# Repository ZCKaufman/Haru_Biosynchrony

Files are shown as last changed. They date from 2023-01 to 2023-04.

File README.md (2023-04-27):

# Haru_Biosynchrony
The Haru Biosynchrony detection device is a pair of devices created by Cameron Middleton, Carmen Hernandez, Dawson Thompson, Jonathan Ott, and Zachary Kaufman at Indiana University for the Intelligent Systems Engineering Senior Capstone (ENGR-E490/E491) course. The device is designed to be used with the Haru social desktop robot prototype by Honda Research Institute, and was created as a tool for the R-House Human-Robot Interaction lab to use for their studies involving intergenerational synchrony during interactions with Haru. 

Contents:
- Hardware Specifications
- Assembly Instructions
- Demo Instructions
- Using the Device
- Running the Code
- Understanding the Output

## Hardware Specifications

## Assembly Instructions

## Demo Instructions

## Using the Device
- This system uses two devices and finds relative bio-synchrony between them. Ensuring that both devices are currently placed on the participants is important for quality metrics of synchrony. 
1. Place the compute module on the top of your non-dominant wrist and secure with velcro strap firmly but not uncomfortably
2. Place the PPG sensor (the one with purple and red wires) on your index finger by slipping your index finger inside the black sleeve so that the red sensor is on the padding at the bottom of your finger
3. Place the PPG sensor (the one with the two thin wires) on your middle and forefinger by slipping those fingers into the black sleeves so that the metal sensors are on the bottom of the center of your finger
4. Place your non-dominant hand (the one with the sensors on it) at your waist if standing, or on your lap if sitting
    - Note: It is best for sensor resolution if the sensors are not moved a lot during the activity, try encouraging participants to keep their non-dominant hand at this position and to use their dominant hand for the activity
5. Now plug in the compute module to the Haru Zotac computer through a USB port and follow the `Running the Code` instructions

## Running the Code
- System Requirements
    - Python 3.10+
    - Ubuntu 20.04
    - ROS Noetic
- Instructions
    1. Open the Arduino IDE in two separate windows
    2. Open a terminal window and run the command `roscore`
    3. In the first window open the file `A_ROS_Arduino.ino` and in the second window open the file `B_ROS_Arduino.ino`
    4. In both windows make sure that the selected board (under Tools) is "Arduino Micro" and the selected port is the port that the Arduino is plugged into
    5. Click the blue/green "Upload" button in the upper left corner of the screen in both windows
    6. Now open two new tabs/windows in terminal and type in the following command for both devices: 'rosrun rosserial_arduino serial_node.py __name:="DevA" _port:=/dev/ttyACM0`
        NOTE: There are two underscores before `name` and one before `port`
        NOTE: Your port may be different, use the one found in the Arduino window for the device you are using under "Tools"
        - Run the same command again but rename the second device to `DevB` and change the port to whatever port the second device is plugged into
    7. Open the Haru_Biosynchrony repository in VSCode 
    8. Open a terminal within VSCode and run the following command `pyenv activate haru_sync`, this will activate the Haru Synchrony Python environment. This environment is installed on the Zotac machines from Honda
    9. Now run the code by entering the following command `python Robot_Code/synchrony.py`
    10. The code should now be running. Every 5 seconds a synchrony metric will be published to ROS and printed into the VS Code terminal
    11. To stop and start over, just click ctrl+c and rerun the command from step 9 (ix)

## Understanding the output
The output from this program will be a metric of synchrony called a Pearson Correlation and it will update the metric every 5 seconds. There will be a score published for heart rate and GSR separately. The metric will be published on ROS as well as printed to the terminal running the program. 
- Negative Score (-1 to 0)
    - A negative score means that the subjects are experiencing negative synchrony, meaning that their heart rate or GSR has an inverse correlation. An inverse correlation means that the subjects' heart rate or GSR data is trending in opposite values from each other. A score of less than -0.5 represents a strong inverse correlation.
- Zero Score (0)
    - A 0 score means that the two participants are neither in sync nor moving out of sync. Their heart rate and GSR data is not correlated.
- Positive Score (0 to 1)
    - A positive score means that the subjects are experiencing synchrony, meaning that their heart rate or GSR has a direct correlation. A score of greater than 0.5 represents a strong correlation.

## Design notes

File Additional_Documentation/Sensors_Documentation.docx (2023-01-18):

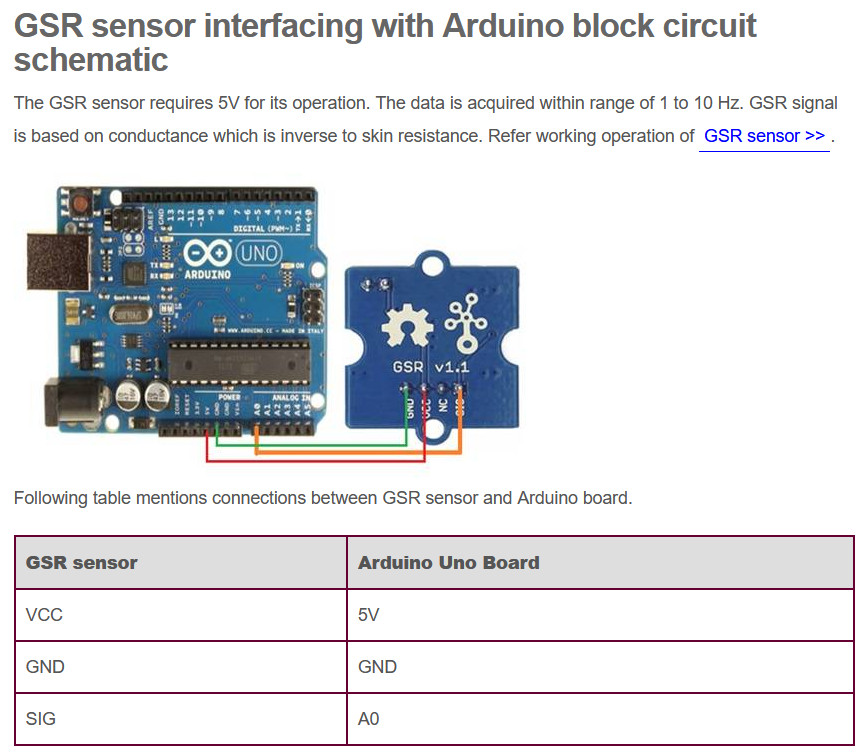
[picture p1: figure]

Source: GSR Interfacing with Arduino Controllers (https://www.rfwireless-world.com/Terminology/GSR-sensor-interfacing-with-Arduino-Code-and-schematic.html)

Sparkfun Pulse Oximeter is more complex than the above GSR board as it interfaces with the Arduino over I2C.

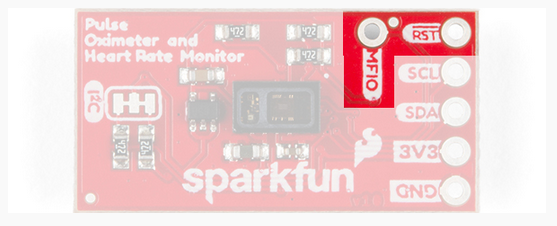
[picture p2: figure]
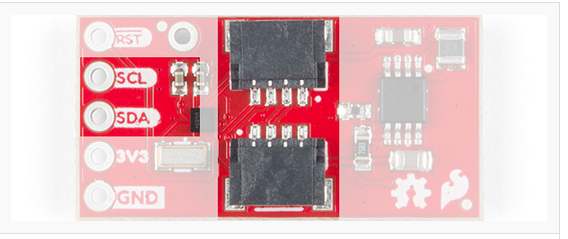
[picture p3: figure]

The board shown is the full Pulse Oximeter. It has a total of 6 pins that need to be connected. 3v3 and Gnd are exactly what they sound like, SCL and SDA form the I2C link to the Arduino (see I2C wiring for Arduino below), and RST and MFIO do not need to be used directly by the end user but must be connected to 2 Digital Arduino pins so the library can control them. The SDA and SCL pins must be connected to the respective SDA and SCL pins on the arduino. I2C works via addressing. This means theoretically, you can have more than one I2C device on a given I2C communication channel. For our project, we will only have the 1 I2C device per arduino, so its unlikely for us to need to deal with this.

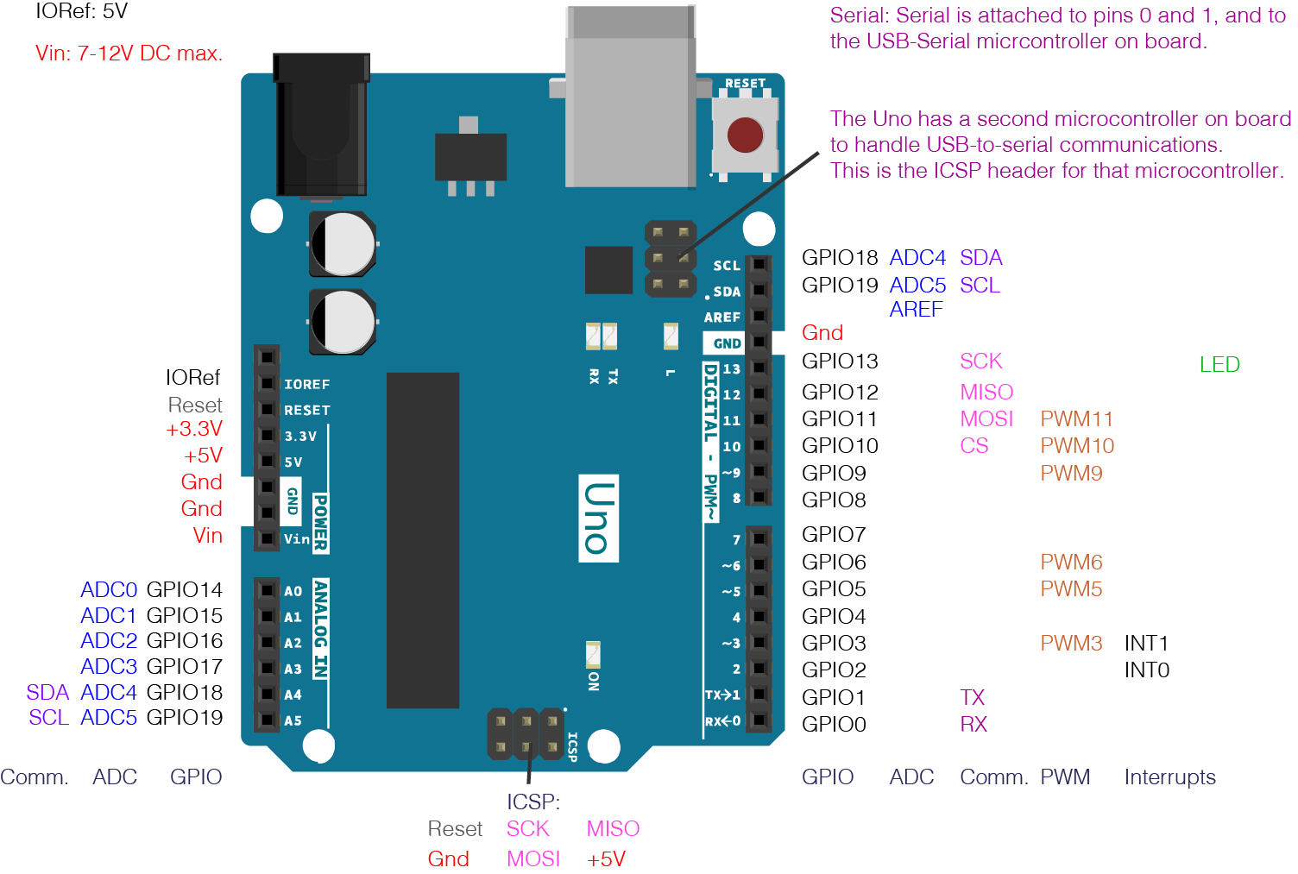
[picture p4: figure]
enter image description here

Once the appropriate connections are made, most of the complexity of the sensor is handled by the provided library. Below is an example of how you would configure the library initially for use. DEF_ADDR is the I2C address used by the sensor. This value should most likely only be what is displayed below, however, another look at the sensor documentation could reveal otherwise. resPin and mfioPin are the digital pins on the Arduino that the respective pins described above are connected to. These values can vary as long as they are updated in the code appropriately. In order to properly pull data from the sensor, you must use <SparkFun_Bio_Sensor_Hub_Library.h>. Examples on how to properly pull data are provided in the source link below.

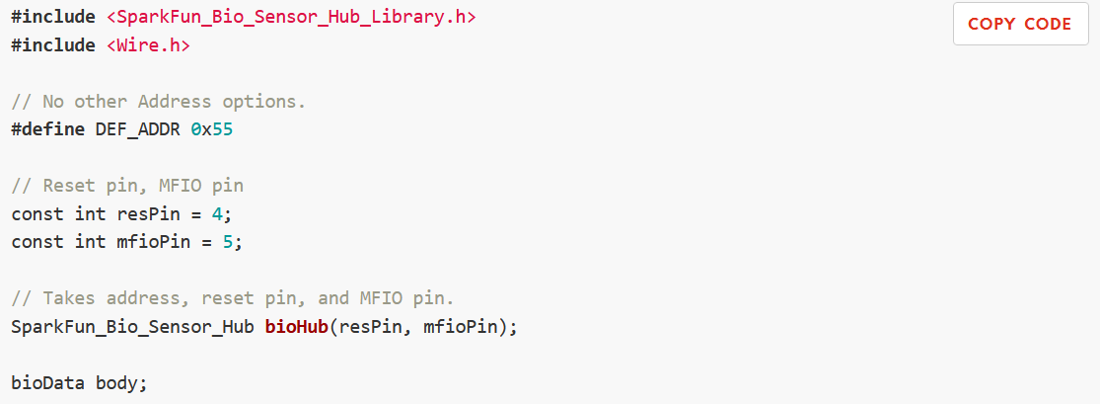
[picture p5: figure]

Source: SparkFun Pulse Oximeter and Heart Rate Monitor Hookup Guide (https://learn.sparkfun.com/tutorials/sparkfun-pulse-oximeter-and-heart-rate-monitor-hookup-guide/all)

Code Examples: SparkFun_Pulse_Oximeter_Heart_Rate_Sensor (https://github.com/sparkfun/SparkFun_Pulse_Oximeter_Heart_Rate_Sensor)

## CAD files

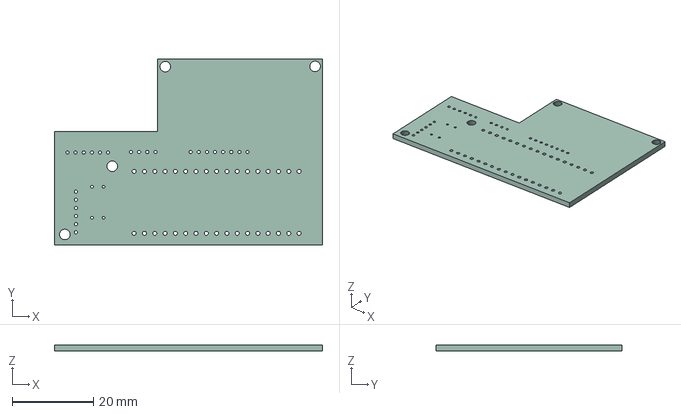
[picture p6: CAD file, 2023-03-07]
Hardware/Prototype_2/PCB/PCB.step
66.0 x 45.7 x 1.60 mm

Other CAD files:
Hardware/Prototype_1/Arduino_Uno v1.f3d
Hardware/Prototype_1/Assembly v19.f3z
Hardware/Prototype_1/Body v21.f3d
Hardware/Prototype_1/Cover v6.f3d
Hardware/Prototype_2/PPG Sleeve v2.f3d
Hardware/Prototype_2/Strain Relief v5.f3d

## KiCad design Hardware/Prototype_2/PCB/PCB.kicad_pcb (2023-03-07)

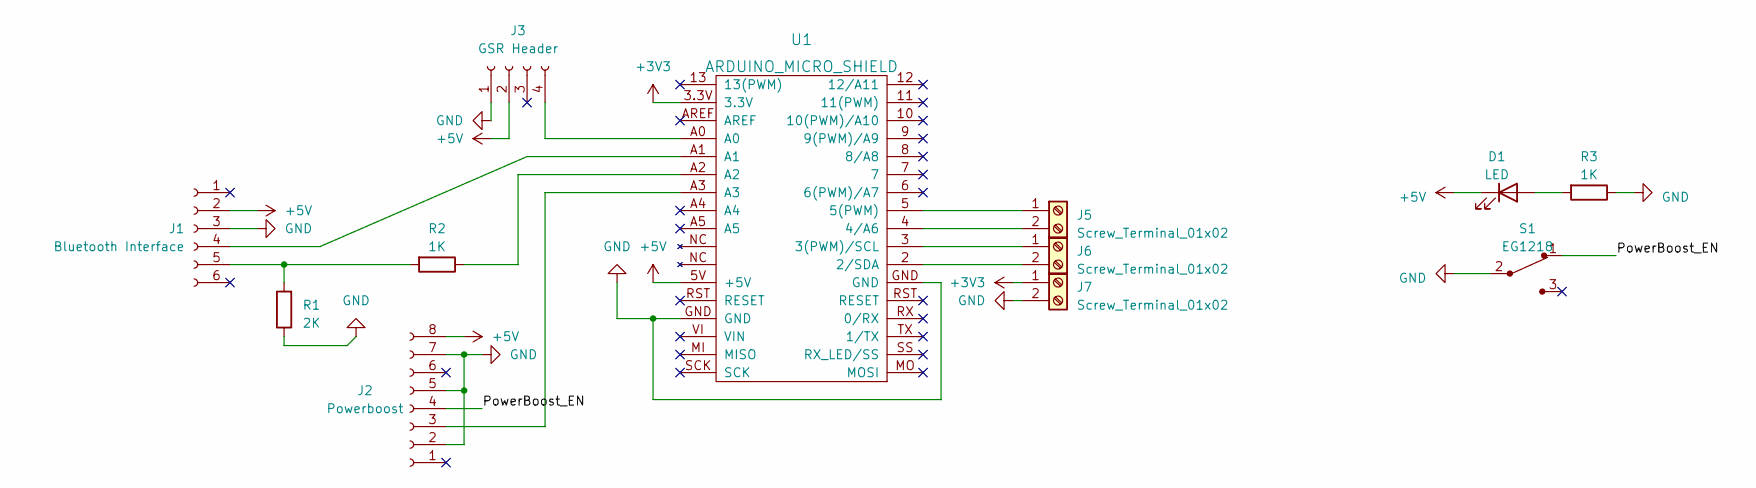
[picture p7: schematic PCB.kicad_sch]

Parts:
D1: LED; LED_D3.0mm_Horizontal_O1.27mm_Z6.0mm
J1: Bluetooth Interface; PinHeader_1x06_P2.00mm_Horizontal
J2: Powerboost; PinSocket_1x08_P2.54mm_Vertical
J3: GSR Header; PinHeader_1x04_P2.00mm_Vertical
J5, J6, J7: Screw_Terminal_01x02; TerminalBlock_Altech_AK300-2_P5.00mm
R1: 2K; R_Axial_DIN0204_L3.6mm_D1.6mm_P7.62mm_Horizontal
R2, R3: 1K; R_Axial_DIN0204_L3.6mm_D1.6mm_P7.62mm_Horizontal
S1: EG1218; Switch_Slide_11.6x4mm_EG1218; MPN EG1218; Digi-Key_PN EG1903-ND
U1: ARDUINO_MICRO_SHIELD

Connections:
+3V3: J7.1, U1.3.3V
+5V: D1.1 (K), J1.2, J2.8, J3.2, U1.5V (+5V)
/PowerBoost_EN: J2.4, S1.1
GND: J1.3, J2.2, J2.5, J2.7, J3.1, J7.2, R1.1, R3.1, S1.2, U1.GND
unnamed: D1.2 (A), R3.2
unnamed: J1.4, U1.A1
unnamed: J1.5, R1.2, R2.2
unnamed: J2.3, U1.A3
unnamed: J3.4, U1.A0
unnamed: J5.1, U1.5 (5(PWM))
unnamed: J5.2, U1.4 (4/A6)
unnamed: J6.1, U1.3 (3(PWM)/SCL)
unnamed: J6.2, U1.2 (2/SDA)
unnamed: R2.1, U1.A2

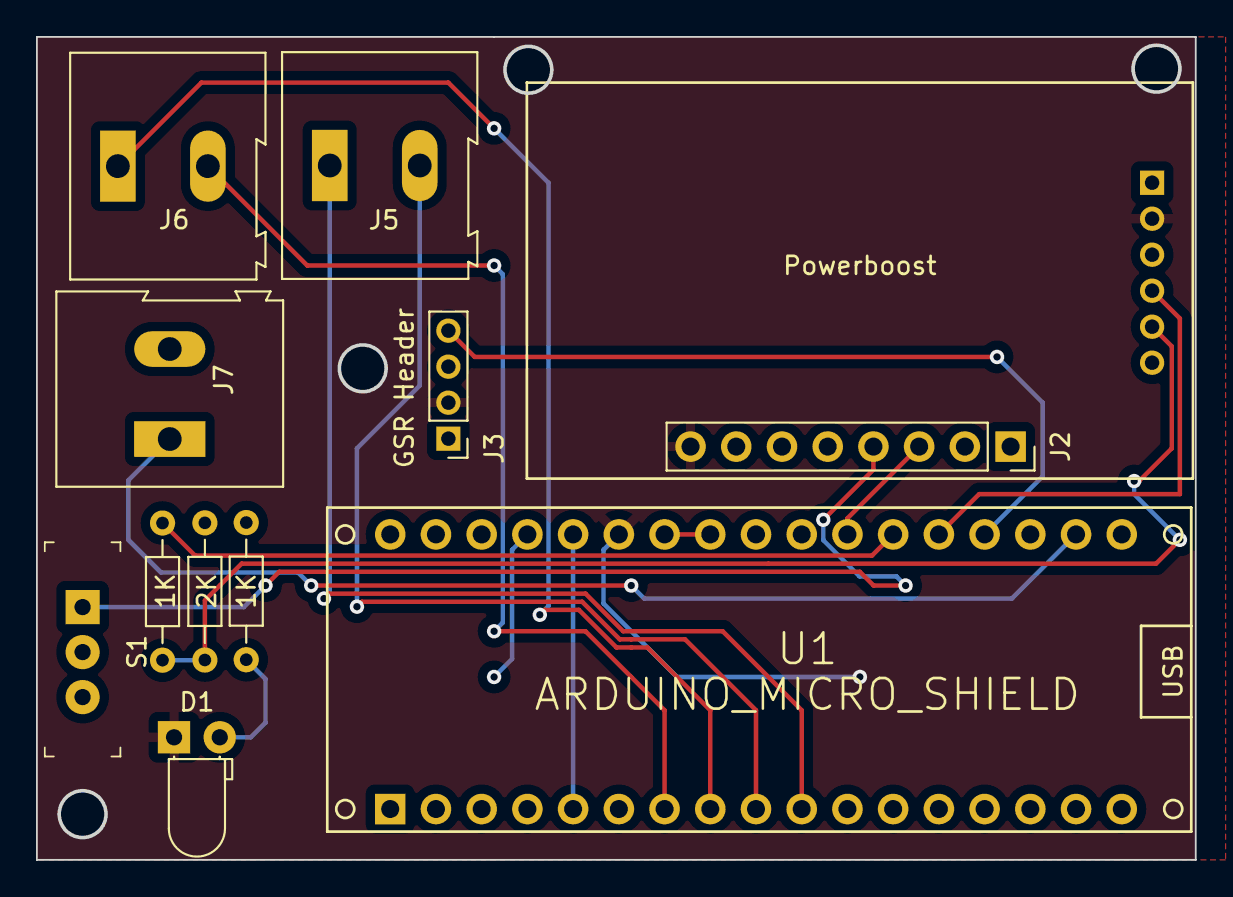
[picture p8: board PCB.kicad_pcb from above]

Board: 2 copper layers, 64.4 x 45.7 mm, 12 parts (1 on the bottom side), 14 nets.

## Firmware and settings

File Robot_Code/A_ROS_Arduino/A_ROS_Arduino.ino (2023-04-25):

#include <SparkFun_Bio_Sensor_Hub_Library.h>
#define USE_USBCON
#include <Wire.h>
#include <ros.h>
#include <std_msgs/Int16.h>

// No other Address options. Does not need to be changed ever.
#define DEF_ADDR 0x55
//encoder_method = "utf-8"

// Creates ROS node handle, which takes care of serial communication and creating publishers and subscribers
ros::NodeHandle nh;
std_msgs::Int16 str_msg;

// Instantiate ROS publishers
ros::Publisher heart_rate("body_A/heart_rate", &str_msg);
ros::Publisher confidence("body_A/confidence", &str_msg);
ros::Publisher oxygen("body_A/oxygen", &str_msg);
ros::Publisher status("body_A/status", &str_msg);
ros::Publisher ext_status("body_A/ext_status", &str_msg);
ros::Publisher r_value("body_A/r_value", &str_msg);
ros::Publisher gsr("body_A/gsr", &str_msg);

// Reset pin, MFIO pin, GSR pin. Change based on appropriate digital / analog arduino pins.
const int resPin = 7;
const int mfioPin = 8;
const int GSRPin = A0;

// Takes address, reset pin, and MFIO pin.
SparkFun_Bio_Sensor_Hub bioHub(resPin, mfioPin); 

bioData body;  
int GSRVal;

void setup(){

  // Modify based on desired baud rate
  Serial.begin(9600); //ros serial uses a baud rate of 57600
  nh.getHardware()->setBaud(57600);

  // ROS Setup
  nh.initNode();
  nh.advertise(heart_rate);
  nh.advertise(confidence);
  nh.advertise(oxygen);
  nh.advertise(status);
  nh.advertise(ext_status);
  //nh.advertise(r_value);
  nh.advertise(gsr);

  Wire.begin();
  int result = bioHub.begin();
  // if (!result)
    // Serial.println("Sensor started!");
  // else
    // Serial.println("Could not communicate with the sensor!!!");

  // Serial.println("Configuring Sensor...."); 
  pinMode(GSRPin, INPUT);
  int error = bioHub.configBpm(MODE_TWO); // Configuring just the BPM settings. 
  if(!error){
    // Serial.println("Sensor configured.");
  }
  else {
    // Serial.println("Error configuring sensor.");
    // Serial.print("Error: "); 
    // Serial.println(error); 
  }
  // Data lags a bit behind the sensor, if you're finger is on the sensor when
  // it's being configured this delay will give some time for the data to catch
  // up. 
  delay(1000); 

}

// The following loop is what we will be using to stream our data via serial to an endpoint.
// The streamed output will take the form of the following string described below:
// "Heartrate,Confidence(HR),Oxygen,Status(Sensor),ExtendedStatus(Sensor),BloodOxygenRValue,GSR\n"
void loop(){

    // Information from the readBpm function will be saved to our "body"
    // variable.  
    body = bioHub.readBpm();
    GSRVal = analogRead(GSRPin);
    // Serial.println(String(body.heartRate) + "," + String(body.confidence) + "," + String(body.oxygen) + "," + String(body.status) + "," + String(body.extStatus) + "," + String(body.rValue) + "," + String(GSRVal) + "\n");
    str_msg.data = body.heartRate;
    heart_rate.publish(&str_msg);

    str_msg.data = body.confidence;
    confidence.publish(&str_msg);

    str_msg.data = body.oxygen;
    oxygen.publish(&str_msg);

    str_msg.data = body.status;
    status.publish(&str_msg);

    str_msg.data = body.extStatus;
    ext_status.publish(&str_msg);

    //str_msg.data = body.rValue;
    //r_value.publish(&str_msg);

    str_msg.data = GSRVal;
    gsr.publish(&str_msg);

    nh.spinOnce();    
    delay(25); // Slowing it down, we don't need to break our necks here.
}

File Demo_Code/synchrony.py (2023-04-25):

import neurokit2 as nk
from scipy import stats
import numpy as np
import pandas
import statistics

data1 = pandas.read_csv("Data_1.csv")
data2 = pandas.read_csv("Data_2.csv")

#from first user
HR_1 = data1['Heartrate'].tolist()
Con_1 = data1['Confidence(HR)'].tolist()
GSR_1_temp = data1['GSR'].tolist() #uncleaned GSR data from user 1
GSR_1_long, ignore1 = nk.eda_process(GSR_1_temp, sampling_rate=40) #processing GSR data from user 1
GSR_1 = GSR_1_long["EDA_Clean"] #processed data from user 1

#from second user
HR_2 = data2['Heartrate'].tolist()
Con_2 = data2['Confidence(HR)'].tolist()
GSR_2_temp = data1['GSR'].tolist() #uncleaned GSR data from user 2
GSR_2_long, ignore2 = nk.eda_process(GSR_2_temp, sampling_rate=40) #processing GSR data from user 2
GSR_2 = GSR_2_long["EDA_Clean"] #processed data from user 2

#removal of unclean HR data, or sub-50% confidence HR data
for m in range(len(HR_1)):
    if Con_1[m] < 50:
        HR_1[m] = 0

for m in range(len(HR_2)):
    if Con_2[m] < 50: 
        HR_2[m] = 0

#Pearson Correlation
GSR_corr = []
PPG_corr = []
GSR_corr = [0 for i in range(len(HR_1))]
PPG_corr = [0 for i in range(len(GSR_1))]

if np.std(HR_1[0:(len(HR_1)-1)]) != 0 and np.std(HR_2[0:(len(HR_2)-1)]) != 0:
    PPG_corr, ignore1 = stats.pearsonr(HR_1[0:len(HR_1)-1], HR_2[0:len(HR_2)-1])
else:
    PPG_corr = 0
if np.std(GSR_1[0:len(GSR_1)-1]) != 0 and np.std(GSR_2[0:len(GSR_2)-1]) != 0:
    GSR_corr, ignore2 = stats.pearsonr(GSR_1[0:len(GSR_1)-1], GSR_2[0:len(GSR_2)-1])
else:
    GSR_corr = 0  


print(PPG_corr)
print(GSR_corr)

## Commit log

2023-01-18 Added Demo Code for PPG Sensor, First Version of Arduino Firmware
2023-01-19 Started PCB for Prototype V2
    [PCB.kicad_pcb, PCB.kicad_sch]
2023-01-24 Added CAD Files for Prototype 1
    [Arduino_Uno v1.f3d, Assembly v19.f3z, Body v21.f3d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]
2023-01-24 Reformatted Prototype 2 Directory Structure
    [PCB.kicad_pcb, PCB.kicad_sch]
2023-02-14 PCB Shape Finalized
    [PCB.kicad_pcb, PCB.kicad_sch]
2023-02-14 Added PCB STEP file
    [PCB.step]
2023-02-28 PCB Final Version, Added Gerber Files
    [PCB-B_Cu.gbl, PCB-B_Mask.gbs, PCB-B_Paste.gbp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]
2023-04-18 Added ROS integrated Arduino code to robot code folder
2023-04-24 Added ROS functionality to synchrony code and created A and B device Arduino code
2023-04-24 Added code to make our Arduino code Micro compatible
2023-04-24 Finalized syncrony functionality for two devices
2023-04-25 Added some Prototype 2 hardware files
    [PPG Sleeve v2.f3d, Strain Relief v5.f3d]
2023-04-27 Fixed threading issue
